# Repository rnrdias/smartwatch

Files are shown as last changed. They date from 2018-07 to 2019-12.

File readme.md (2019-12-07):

# Smartwatch
É um relógio inteligente para micro controlador ATMEGA328P e display gráfico Nokia 5110.

#### Características:
- Data/Hora
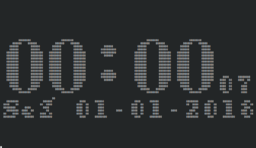
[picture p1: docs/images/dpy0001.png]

- Alarme - Hora - Dia da semana
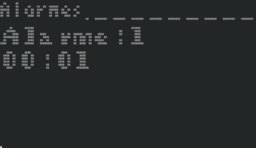
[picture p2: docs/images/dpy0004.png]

- Cronometro - Start,Stop e step
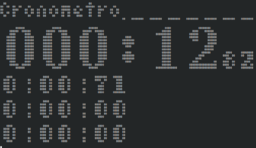
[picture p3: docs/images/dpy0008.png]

- Calendário
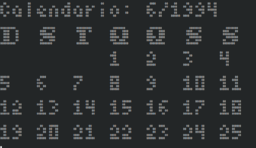
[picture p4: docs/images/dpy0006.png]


#### Motor gráfico:
- Lista
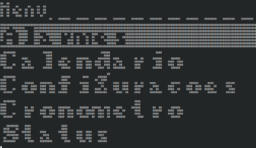
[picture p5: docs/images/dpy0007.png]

- Definir valor
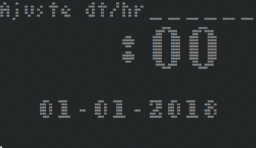
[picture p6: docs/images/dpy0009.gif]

- Definir valor sobre a lista
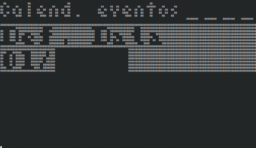
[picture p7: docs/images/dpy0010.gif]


#### Estrutura de pastas do projeto
- electric: contem os esquemas elétrico e o layout
- docs: informações gerais e datasheets
- mechanic: projeto mecânico, posicionamento dos componentes
- firmware: contem o código fonte do smartwatch, compilação para AVR ou PC(simulador).

#### Detalhes do firmware:
+ app: aplicações executadas em segundo plano
+ build: binários gerados
+ kernel: núcleo do sistema
   + drivers: contem as interfaces e implementações dos hardwares
        + simulador: drivers para o simulador
        + atmega328p: drivers para o atmega328p
   + fonts: armazenamento de fontes
   + screen: telas do sistema
   + settings: definição das configurações e ligação das funções
   + upp: definição de funções para manipulação de gráficos baixo nível
+ language: definição dos idiomas
+ screens: telas para usuário final

#### Compilação:
Para o simulador:
```sh
$ make all_simulator
```
Para o avr:
```sh
$ make all_avr
```
Para recompilação (remove os arquivos binários e objetos):
```sh
$ make clean
```

#### Para o futuro:
+ integração com sistema Android, Bluetooth
    + sincronização das notificações
    + sincronização do calendário
    + identificação de ligações o número de telefone
+ controle de eletrodomésticos por infravermelho
+ contador de passos

### Licença
Copyright (c) 2015-2019 Ranieri Dias 
Todos os direitos reservados
Este arquivo é parte de Smartwatch.

O Smartwatch é um software livre: você pode redistribuí-lo e / ou modificar
sob os termos da Licença Pública Geral GNU, publicada pela
Free Software Foundation, versão 3 da Licença ou
(a seu critério) qualquer versão posterior.
O Smartwatch é distribuído na esperança de que seja útil,
mas SEM QUALQUER GARANTIA; sem sequer a garantia implícita de
COMERCIALIZAÇÃO ou ADEQUAÇÃO PARA UMA FINALIDADE ESPECÍFICA. Veja o
GNU General Public License para mais detalhes.
Você deveria ter recebido uma cópia da Licença Pública Geral GNU
junto com o Smartwatch. Caso contrário, consulte http://www.gnu.org/licenses/.

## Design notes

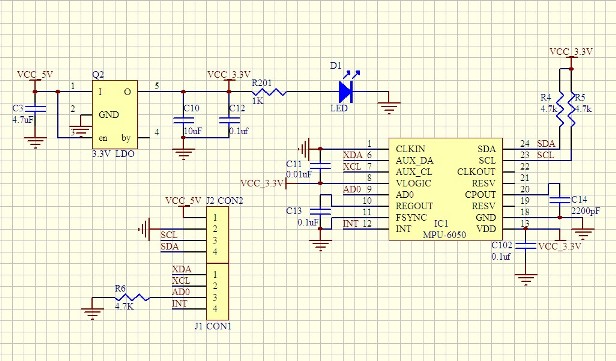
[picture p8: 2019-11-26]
docs/datasheet/MPU6050-V1-SCH-menor.jpg

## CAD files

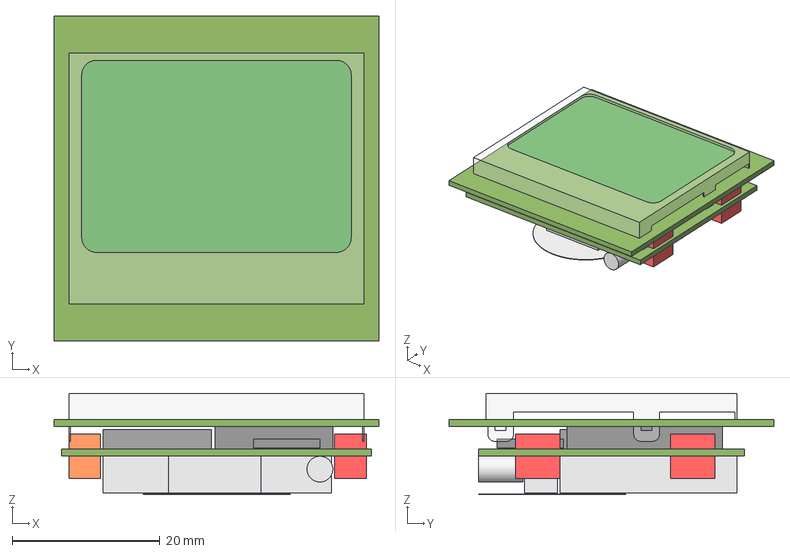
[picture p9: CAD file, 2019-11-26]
mechanic/smartwatch.FCStd
44.0 x 44.0 x 13.7 mm
bat2
screen
base
pcb001
pcb
ci
mod
giro
button0
button1
button2
button3
LedIr
Vibra
Buzz

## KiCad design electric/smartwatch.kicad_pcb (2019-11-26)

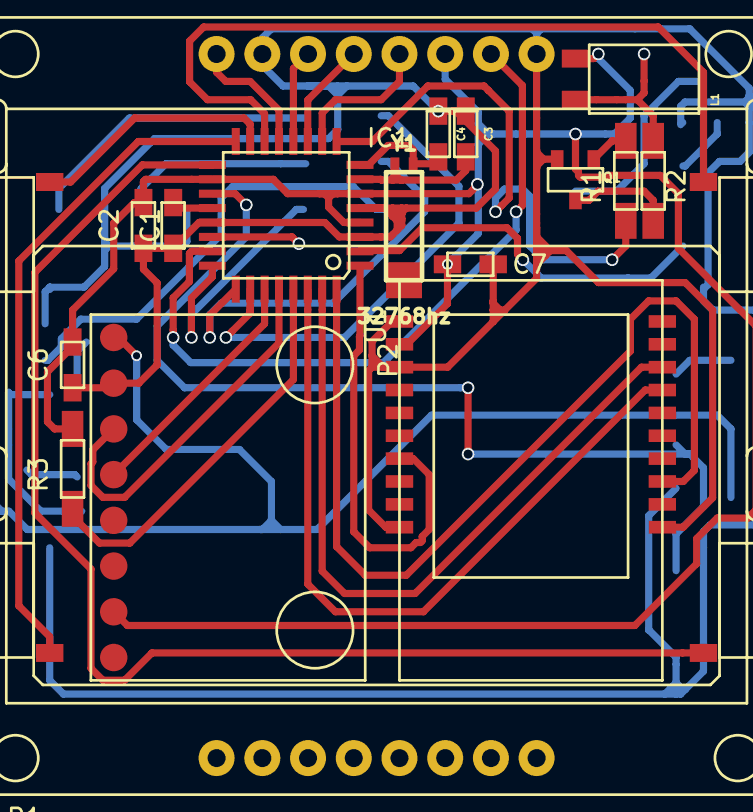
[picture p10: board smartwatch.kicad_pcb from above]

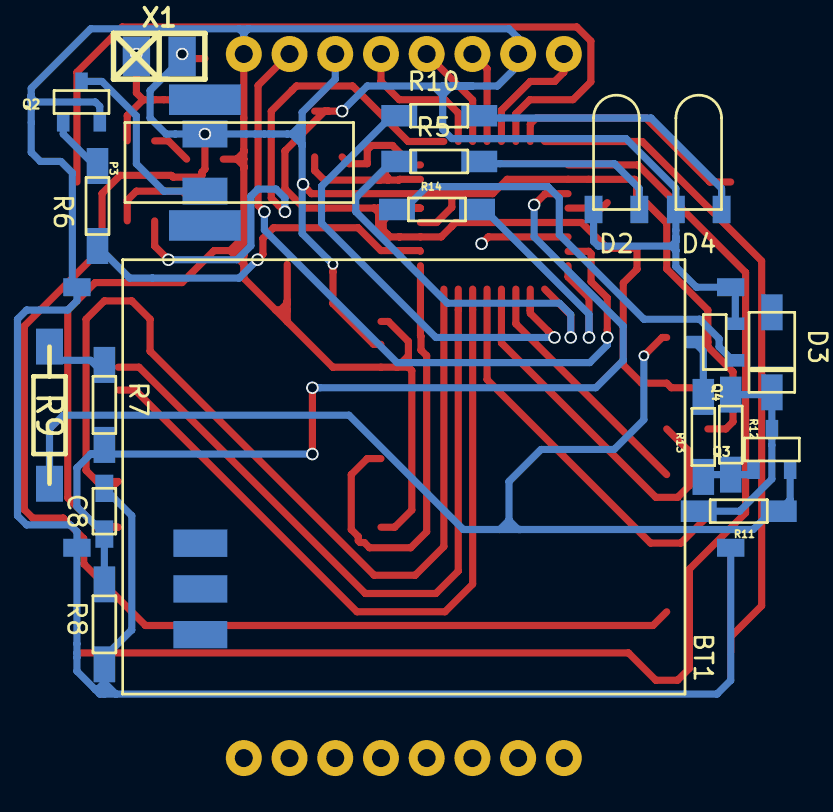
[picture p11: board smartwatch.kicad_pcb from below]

Board: 2 copper layers, 40 parts (20 on the bottom side), 40 nets.

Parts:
BT1: 3,8V/380mA; Bat_3.8V
C1: 10nF; Cap_SMD
C2, C6, C7, C8: 100nF; Cap_SMD
C3, C4: 6pF; Cap_SMD
D2: LED_POWER; LED_H
D3: D; D_SMD
D4: LED_IR; LED_H
IC1: ATMEGA328P-A; 32A
L1: 15mH; Indutor_15mH
P1: NOKIA_5110; LCD_nokia5110
P2: MPU6050
P3: VIRBRATOR; Vibr
Q1, Q2, Q4: BC337; SOT23
Q3: BC237; SOT23
R1, R6, R13, R14: 470R; R_SMD
R2, R5, R10: 100R; R_SMD
R3: 10K; R_SMD
R7: 300K; R_SMD
R8: 100K; R_SMD
R9: 10R/0,5W; RC03_SMD
R11: 270R; R_SMD
R12: 1K; R_SMD
SW1, SW2: SW_PUSH; Button_Horizontal_pin_mirror
SW3, SW4: SW_PUSH; Button_Horizontal
U1: E104-BT02
X1: Buzz; pin_socket_2_smd
Y1: 32768hz; crystal_tc-26_horiz

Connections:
+BATT: P2.1, Q3.2, R9.2, R11.2
ACC_SCL: IC1.28, P2.3
ACC_SDA: IC1.27, P2.4
BAT_RECARGA: IC1.24, R14.1
BAT_VOLT: C8.1, IC1.19, R7.1, R8.2
BLUE_D/C: IC1.32, U1.3
BLUE_RX: IC1.31, U1.8
BLUE_S/~M: IC1.1, U1.17
BLUE_TX: IC1.30, U1.7
BUT_A: IC1.14, SW1.1
BUT_B: IC1.15, SW4.1
BUT_C: IC1.16, SW2.1
BUT_D: IC1.17, SW3.1
BUZ: IC1.9, R1.2
CLOCK_1A: C3.1, IC1.7, Y1.1
CLOCK_1B: C4.1, IC1.8, Y1.2
FIRM_UPDADE_RESET: IC1.29, R3.2
IR_LED: IC1.26, R10.2
LCD_D/~C: IC1.12, P1.3
LCD_LAMP: IC1.23, P1.7
LCD_REST: IC1.13, P1.1
LCD_SCE: BT1.2, C1.2, C2.2, C3.2, C4.2, C6.2, C7.2, C8.2, D2.1, D4.1, IC1.3, IC1.5, IC1.21, P1.2, P1.8, P2.2, Q1.2, Q2.2, Q4.2, R8.1, SW1.2, SW2.2, SW3.2, SW4.2, U1.1, U1.11, U1.13, U1.20
LCD_SCLK: IC1.10, P1.5
LCD_SDIN: IC1.11, P1.4
unnamed: BT1.1, R7.2, R9.1
unnamed: C1.1, IC1.20
unnamed: D2.2, R5.1
unnamed: D3.1, Q3.3, R11.1, R12.2
unnamed: D4.2, R10.1
unnamed: L1.1, R2.1, X1.1
unnamed: P3.2, Q2.3
unnamed: Q1.1, R1.1
unnamed: Q1.3, R2.2
unnamed: Q2.1, R6.1
unnamed: Q3.1, R12.1, R13.2
unnamed: Q4.1, R14.2
unnamed: Q4.3, R13.1
POWER_LED: IC1.25, R5.2
VCC: C2.1, C6.1, C7.1, IC1.4, IC1.6, IC1.18, L1.2, P1.6, P2.7, P3.1, R3.1, U1.12, X1.2
VIBRA: IC1.2, R6.2

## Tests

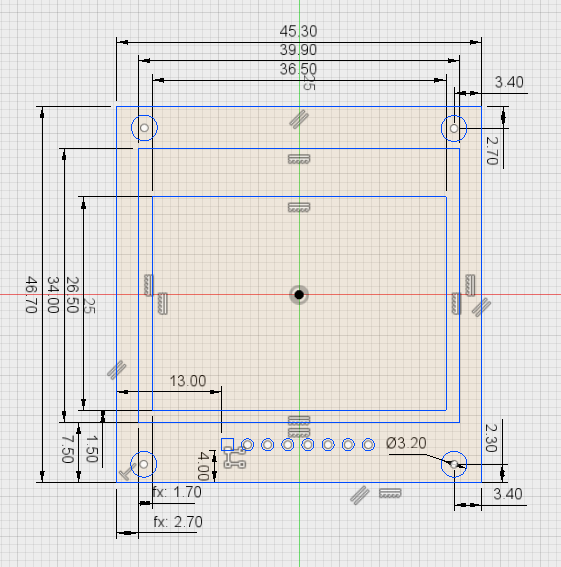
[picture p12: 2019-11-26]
docs/datasheet/nokia-5110-display-measurements.png

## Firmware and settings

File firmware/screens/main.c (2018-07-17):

/*
 * To change this license header, choose License Headers in Project Properties.
 * To change this template file, choose Tools | Templates
 * and open the template in the editor.
 */

#include "screens.h"
#include "../app/status_bar/status_bar.h"
#include "../kernel/drivers/lcd.h"
#include "../kernel/energy_management.h"

CONST char dsHour[] = "%w%1d:%1d%w\n\n%1d\r\n";
CONST char dsDate[] = "%s %1d-%1d-%3d";

void Sc_mainPrintIcon(const StatusBar_paramFormat *s, void *parameter) {
    Std_printf("%w%c", (char*) RVCW(&s->icon), 0);
    *(void **) parameter = (StatusBar_paramFormat *) s;
}

void Sc_mainLoop(Screen_windowLoad *this) {
    StatusBar_paramFormat *SB_last = 0;
    static TMS_timeFormat t;
    static StatusBar_paramFormat *SB_lastPre = 0;

    char *weekday = (char *) (&lang->sunday + RTC_getWeekday());
    weekday = (char *) RVCW(weekday);
    Std_printf("%r");
    StatusBar_check(Sc_mainPrintIcon, &SB_last);
    UPP_setCursorXY(1, 1);
    Std_printf(_LC(dsHour), &Font_numeric_24, RTC_date.hour, RTC_date.minute, &Font_alfanum_8, RTC_date.second);
    Std_printf(_LC(dsDate), weekday, RTC_date.day, RTC_date.month, RTC_date.year);

    if (SB_last != SB_lastPre) {
        t = 3000;
        TMS_loadTime(&t);
        SB_lastPre = SB_last;
    } else if (SB_last && !TMS_checkTime(&t)) {
        Std_printf("%w%c%w%s", RVCW(&SB_last->icon), 0, &Font_alfanum_8, (char*) RVCW(&SB_last->title));
    }

    if (Keyboard_keyEnter()) {
        Screen_windowLoad scLoad;
        scLoad.parameters = 0;
        scLoad.windows = &Sc_menu;
        Screen_windowOpen(&scLoad);
    }

    if (Keyboard_keyEsc()) {
        Screen_windowLoad scLoad;
        scLoad.parameters = 0;
        scLoad.windows = &Sc_status;
        Screen_windowOpen(&scLoad);
    }
    EM.timeStandbay = TMS_INT_SEC; //1fps
}
Screen_window Sc_main = {0, Sc_mainLoop, 0, 0, 0, 0};

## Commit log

2018-05-16 bip driver ok
2018-05-29 adição de onResume onPause nos screens (redução da alocação de memoria)
2018-06-01 remocao de arquivo nao necessario
2018-06-01 mudança para suporte const _ parcial
2018-06-03 const para demais telas
2018-06-26 mudanca para o linux
2018-07-10 funcoes de controle EventHandler
2018-07-11 nova estrutura para memoria
2018-07-14 reorganização da estrutura de diretorios
2018-07-15 alteracao para a sincronizacao do arquivo
2018-07-15 screen bug de memoria correcao, alocacao dinamica de memoria
    [main.c]
2018-07-17 Gerenciamento de energia
2019-08-19 Alterações para execução sem problemas
    [main.c]
2019-11-24 make clean - interrupt simulator
2019-11-26 add files mechanic, docs and electric
    [smartwatch.FCStd, smartwatch.kicad_pcb, smartwatch.sch]
